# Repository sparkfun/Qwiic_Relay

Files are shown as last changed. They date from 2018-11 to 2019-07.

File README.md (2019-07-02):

SparkFun Qwiic Single Relay
========================================

SparkFun Qwiic Single Relay

[*SparkFun Qwiic Single Relay (COM-15093)*](https://www.sparkfun.com/products/15093)
Have you ever wanted to control something powerful? Have you ever needed to turn on/off a high voltage device from your Arduino? Now you can with the Qwiic Relay! This device allows you to control large power loads with simple I<sup>2</sup>C commands. The Qwiic Relay can handle 10 Amps at 120 Volts AC, perfect for large inductive loads like DC motors or blenders.

The Qwiic Relay comes with a default I<sup>2</sup>C address but can be changed with a simple command allowing you to control over 100 Qwiic Relays on a single bus!<sup>[1](#powerWarning)</sup>

The Qwiic Relay comes fully assembled and uses the simple [Qwiic](https://www.sparkfun.com/qwiic) interface. No soldering, no voltage translation, no figuring out which pin is SDA or SCL, just plug and go!

<div class="alert alert-warning"><b>Note:</b> Controlling high voltage (110/220VAC) requires certain precautions. A beginner can do it but if you're unsure then please consider the pre-made <a href="https://www.sparkfun.com/products/14236">IoT Power Relay</a>. It's not I<sup>2</sup>C but the IoT Power Relay contains shielding to prevent accidental shock.</div>

Footnote 1: Toggling lots of relays on a 3.3V bus can cause voltage spikes. An external power supply will be required.

Repository Contents
-------------------

* **/Documents** - Datasheets
* **/Firmware** - Latest firmware and examples. 
* **/Hardware** - Eagle design files (.brd, .sch)

Documentation
--------------
* **[Hookup Guide](https://learn.sparkfun.com/tutorials/qwiic-single-relay-hookup-guide)** - Basic hookup guide

Arduino Library
--------------
* **[SparkFun Qwiic Relay Arduino Library](https://github.com/sparkfun/SparkFun_Qwiic_Relay_Arduino_Library)** - SparkFun Arduino Library for controlloing the Qwiic Single and Quad Relay

License Information
-------------------

This product is _**open source**_! 

Please review the LICENSE.md file for license information. 

If you have any questions or concerns on licensing, please contact techsupport@sparkfun.com.

Please use, reuse, and modify these files as you see fit. Please maintain attribution to SparkFun Electronics and release under the same license.

Distributed as-is; no warranty is given.

- Your friends at SparkFun.

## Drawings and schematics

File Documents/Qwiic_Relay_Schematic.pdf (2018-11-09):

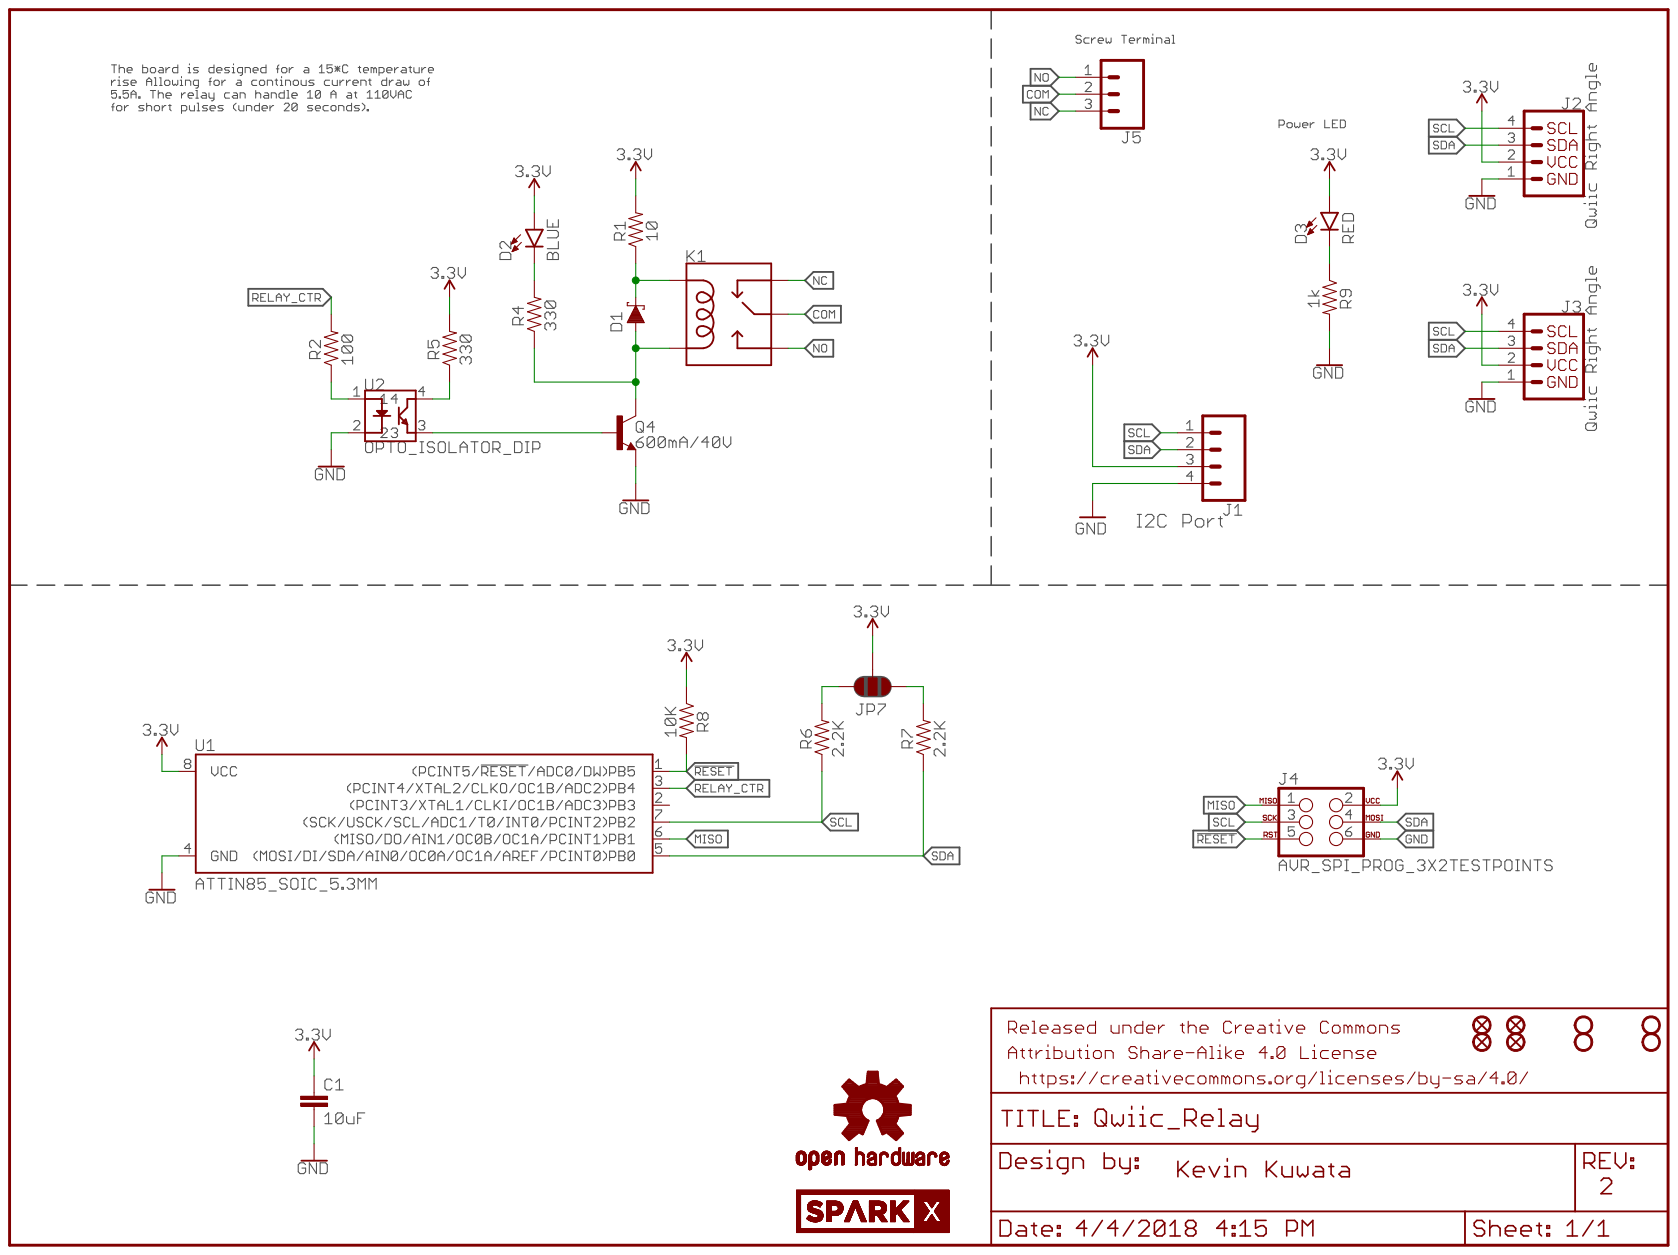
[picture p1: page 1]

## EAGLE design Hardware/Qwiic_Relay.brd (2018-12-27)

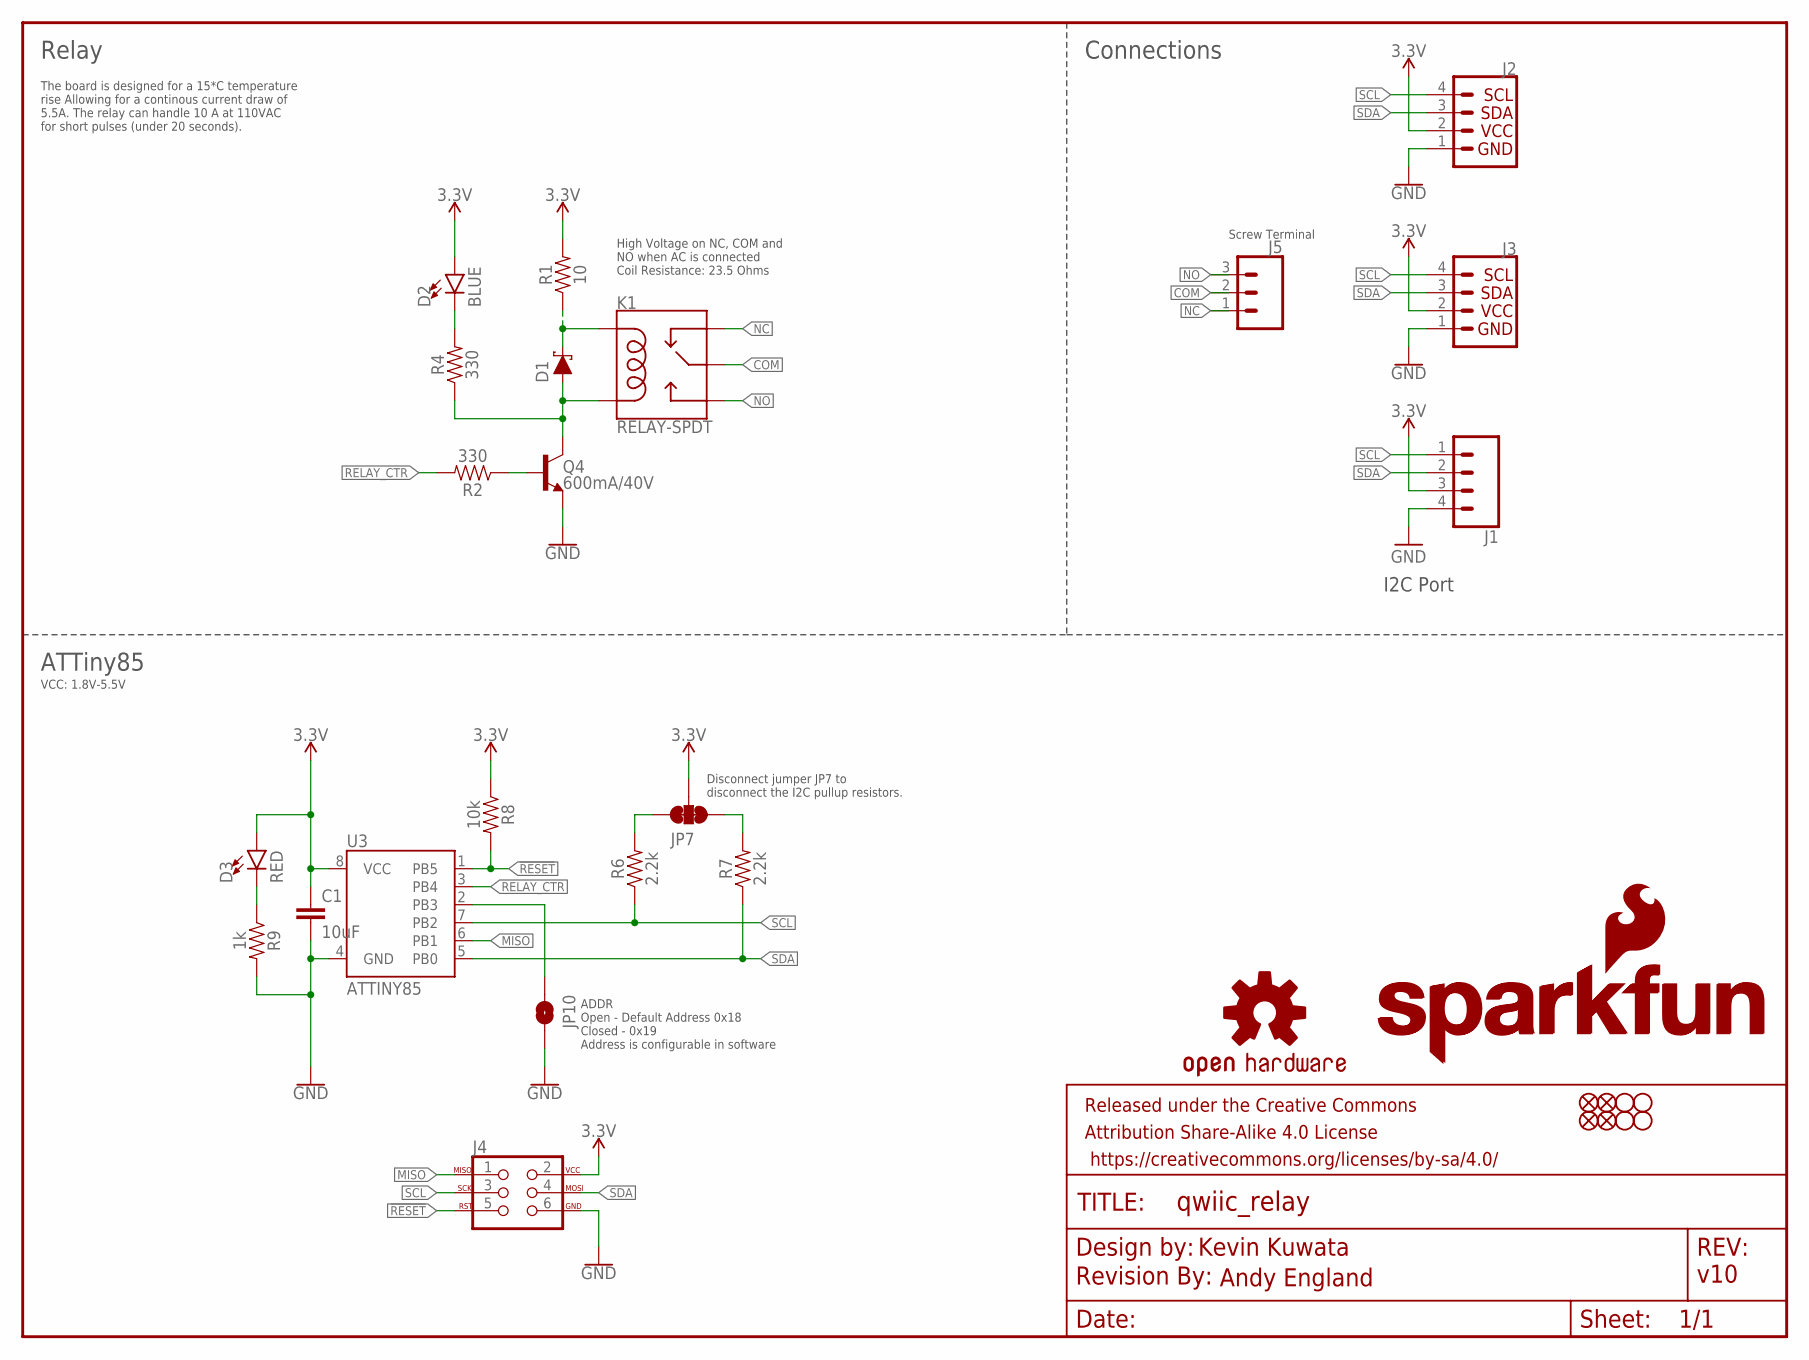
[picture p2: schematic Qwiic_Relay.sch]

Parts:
C1: 10uF; 0603
D1: 1A/23V/620mV; SOD-323
D2: BLUE; LED-0603
D3: RED; LED-0603
FRAME1: FRAME-LETTER; CREATIVE_COMMONS
J1: CONN_041X04_NO_SILK; 1X04_NO_SILK
J2, J3: QWIIC_CONNECTORJS-1MM; 1X04_1MM_RA
J4: AVR_SPI_PROG_3X2TESTPOINTS; 2X3_TEST_POINTS
J5: CONN_03-SCREW-5MM; SCREWTERMINAL-5MM-3
JP1, JP3, JP4, JP5: STAND-OFF
JP2, JP6, JP8, JP9: FIDUCIALUFIDUCIAL; MICRO-FIDUCIAL
JP7: JUMPER-SMT_3_2-NC_TRACE_NO-SILK; SMT-JUMPER_3_2-NC_TRACE_NO-SILK
JP10: JUMPER-SMT_2_NO_NO-SILK; SMT-JUMPER_2_NO_NO-SILK
K1: RELAY-SPDT; RELAY_G5LE
LOGO1: OSHW-LOGOMINI; OSHW-LOGO-MINI
LOGO2: REVISION
Q4: 600mA/40V; SOT23-3
R1: 10; 0603
R2, R4: 330; 0603
R6, R7: 2.2k; 0603
R8: 10k; 0603
R9: 1k; 0603
U3: ATTINY85
U$3: SFE_LOGO_NAME.1_INCH; SFE_LOGO_NAME_.1
U$4: SFE_LOGO_NAME_FLAME.1_INCH; SFE_LOGO_NAME_FLAME_.1

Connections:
3.3V: C1.1, D2.A, D3.A, J1.3, J2.2, J3.2, J4.2, JP7.2, R1.2, R8.1, U3.8 (VCC)
!RESET: J4.5, R8.2, U3.1 (PB5)
COM: J5.2, K1.1 (MAIN)
GND: C1.2, J1.4, J2.1, J3.1, J4.6, JP10.2, Q4.2 (E), R9.2, U3.4 (GND)
MISO: J4.1, U3.6 (PB1)
unnamed: Q4.1 (B), R2.1
unnamed: D1.A, K1.5 (COIL2), Q4.3 (C), R4.1
unnamed: JP7.1, R7.2
unnamed: JP10.1, U3.2 (PB3)
unnamed: D1.C, K1.2 (COIL1), R1.1
unnamed: D2.C, R4.2
unnamed: JP7.3, R6.2
unnamed: D3.C, R9.1
NC: J5.1, K1.4 (NC)
NO: J5.3, K1.3 (NO)
RELAY_CTR: R2.2, U3.3 (PB4)
SCL: J1.1, J2.4, J3.4, J4.3, R6.1, U3.7 (PB2)
SDA: J1.2, J2.3, J3.3, J4.4, R7.1, U3.5 (PB0)

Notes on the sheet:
Kevin Kuwata
v10
Screw Terminal
I2C Port
The board is designed for a 15*C temperature rise Allowing for a continous current draw of 5.5A. The relay can handle 10 A at 110VAC for short pulses (under 20 seconds).
ADDR Open - Default Address 0x18 Closed - 0x19 Address is configurable in software
Andy England
ATTiny85
Relay
Connections
Disconnect jumper JP7 to disconnect the I2C pullup resistors.
VCC: 1.8V-5.5V
High Voltage on NC, COM and NO when AC is connected Coil Resistance: 23.5 Ohms

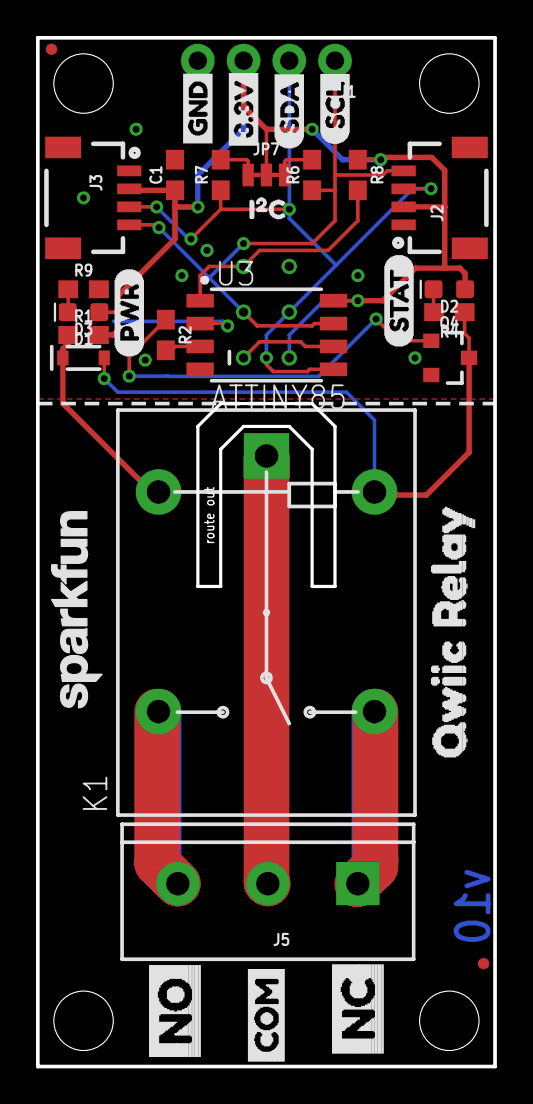
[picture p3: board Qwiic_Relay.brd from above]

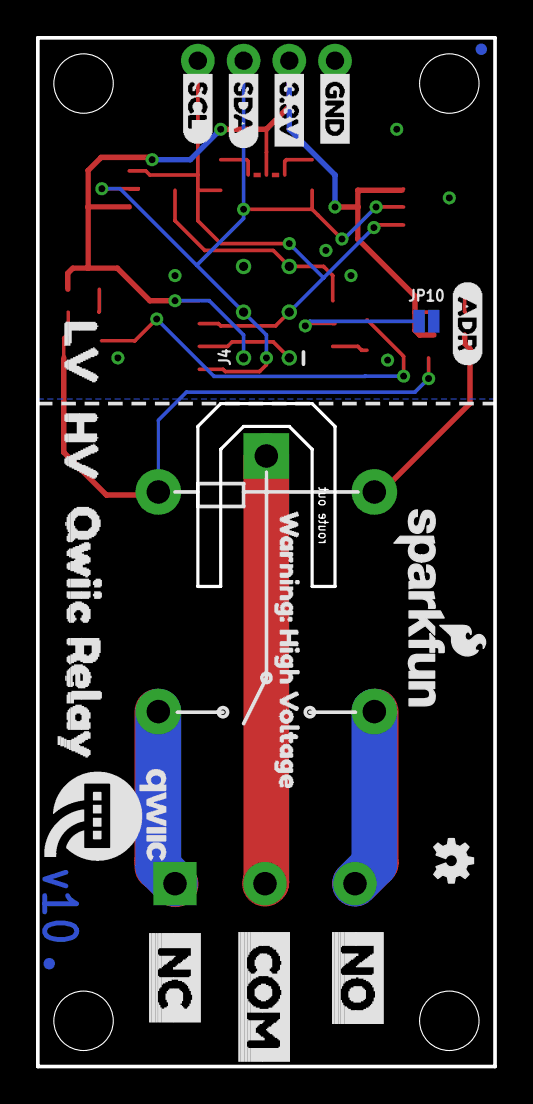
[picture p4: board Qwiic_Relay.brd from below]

Board: 2 copper layers, 25.4 x 57.1 mm, 60 parts (19 on the bottom side), 18 nets.

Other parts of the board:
U$1: QWIIC-LOGO-MEDIUM
U$2: (PWR)
U$5: SCL
U$6: SDA
U$7, U$22: 3.3V
U$8, U$13: GND
U$9: (ADR)
U$10: ORDERING_INSTRUCTIONS
U$11, U$18: NO2
U$12: COM7
U$14: I__C1
U$15, U$16: _QWIIC_RELAY0
U$17, U$20: NC3
U$19: COM4
U$21: 20
U$23: SCL1
U$24: SDA0
U$25: STAT1
U$26: WARNING#_HIGH_VOLTAGE0
U$27: HV2
U$28: LV1

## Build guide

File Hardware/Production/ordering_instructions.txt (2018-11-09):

panel size, 78x103mm
PCB thickness, 1.6mm
number of layers, 2
soldermask color, Black
silkscreen color, White
oz copper, 1oz
finish, HASL lead free
stencils, top

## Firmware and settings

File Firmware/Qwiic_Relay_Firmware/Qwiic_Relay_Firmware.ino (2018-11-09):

/******************************************************************************
  Qwiic Relay Firmware
  Kevin Kuwata @ SparkX
  March 21, 2018
  https://github.com/sparkfunX/Qwiic_Relay
  Arduino 1.8.5

  This is the firmware on the Qwiic Relay. The default I2C Address is
  0x18;

******************************************************************************/
#include <TinyWire.h> //https://github.com/lucullusTheOnly/TinyWire
#include <EEPROM.h>


#define RELAY_PIN   4
 
#define SETTING_LOCATION_ADDRESS	1

volatile byte qwiicRelayAddress  =    0x18; //default

const byte relayAddressPin	=	3;



#define COMMAND_RELAY_OFF 			0x00
#define COMMAND_RELAY_ON 			0x01
#define COMMAND_CHANGE_ADDRESS 		0x03
#define COMMAND_FIRMWARE_VERSION 	0x04
#define COMMAND_STATUS 				0x05
#define COMMAND_HAS_BEEN_CHECKED 	0x99

const byte firmwareVersionMajor = 1;
const byte firmwareVersionMinor = 1;

volatile byte command = COMMAND_HAS_BEEN_CHECKED;
volatile byte address = COMMAND_HAS_BEEN_CHECKED;


void setup() {
	
  pinMode(relayAddressPin, INPUT);
  digitalWrite(relayAddressPin, HIGH); //internal pull up
  
  pinMode(RELAY_PIN, OUTPUT);
  digitalWrite(RELAY_PIN, LOW);
  
	
	if(digitalRead(relayAddressPin) == 0){
		qwiicRelayAddress = 0x19;
	}
	else{
  //Read EEPROM, is it empty (0xFF)? or does it have a value?
  qwiicRelayAddress =  EEPROM.read(SETTING_LOCATION_ADDRESS);
		if (qwiicRelayAddress == 0xFF) {
			//EEPROM has never been written before, use the default address 0x18.
		qwiicRelayAddress = 0x18; //default
		}
	}

  TinyWire.begin(qwiicRelayAddress);
  TinyWire.onReceive(receiveEvent); // register event
  TinyWire.onRequest(onI2CRequest);
}

void loop() {
}

/*========================================================*/
//        ISR
/*========================================================*/

// When the master initiates a command and data to slave
//		ie) the master says 0x01, then sends a 1, means command: 0x01 then the slave listens for the next thing, which is the relay state 1
void receiveEvent(int bytesReceived) {
  byte count = 0;
  while (TinyWire.available() > 0) {
    if (count == 0) {
      command = TinyWire.read();

      if (command == COMMAND_RELAY_ON) {
        digitalWrite(RELAY_PIN, HIGH);
        command = COMMAND_HAS_BEEN_CHECKED;
      }
      else if (command == COMMAND_RELAY_OFF) {
        digitalWrite(RELAY_PIN, LOW);
        command = COMMAND_HAS_BEEN_CHECKED;
      }
    }
    else if (count == 1) {
      if (command == COMMAND_CHANGE_ADDRESS) {
        byte address = TinyWire.read();

        if (address > 0x07 && address < 0x78) {
          //valid address, update and save to EEPROM
          qwiicRelayAddress = address;

          EEPROM.write(SETTING_LOCATION_ADDRESS, qwiicRelayAddress);
          TinyWire.begin(qwiicRelayAddress);
        }
      }
    }
    else {
      TinyWire.read(); //read the data coming in but ignore it.
    }
    count++;
  }
}// end of receive ISR



//When the master requests data from the slave, this
//    ISR is triggered.

void onI2CRequest() {
  //not sure if this will work because the master sends 0x04, then the salve enters the RX event isr
  // then goes to main, sets the flag. then if that happens slower than versionFlag we have a race condition.
  if (command == COMMAND_FIRMWARE_VERSION) {
    //TinyWire.send(firmwareVersion);// tiny wire can't send multiple bytes.
    TinyWire.send(firmwareVersionMajor);
    TinyWire.send(firmwareVersionMinor);

    command = COMMAND_HAS_BEEN_CHECKED;
  }
  else if (command == COMMAND_STATUS) {
    if (digitalRead(RELAY_PIN) == HIGH)
      TinyWire.send(COMMAND_RELAY_ON);
    else
      TinyWire.send(COMMAND_RELAY_OFF);

    command = COMMAND_HAS_BEEN_CHECKED;
  }
}

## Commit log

2018-11-12 pre review
    [Qwiic_Relay.brd, Qwiic_Relay.sch]
2018-11-13 changing to most recent rev
    [Qwiic_Relay.brd, Qwiic_Relay.sch]
2018-11-14 post review
    [Qwiic_Relay.brd, Qwiic_Relay.sch]
2018-11-15 post-qc review
    [Qwiic_Relay.brd]
2018-11-19 moving high voltage silk
    [Qwiic_Relay.brd]
2018-12-27 updating prod_id of relay to proper prod_id
    [Qwiic_Relay.brd, Qwiic_Relay.sch]
2019-07-02 Removes Example Code which now lives in the SparkFun Qwiic Relay Arduino Library, and updates the readme with a link to it

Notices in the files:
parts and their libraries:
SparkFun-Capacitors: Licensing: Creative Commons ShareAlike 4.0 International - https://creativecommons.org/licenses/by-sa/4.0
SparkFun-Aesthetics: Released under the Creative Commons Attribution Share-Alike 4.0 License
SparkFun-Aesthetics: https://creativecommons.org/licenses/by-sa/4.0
